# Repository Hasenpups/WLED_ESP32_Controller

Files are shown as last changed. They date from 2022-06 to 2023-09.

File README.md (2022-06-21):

Shield: [][cc-by-nc-sa]

This work is licensed under a
[Creative Commons Attribution-NonCommercial-ShareAlike 4.0 International License][cc-by-nc-sa].

[][cc-by-nc-sa]

[cc-by-nc-sa]: http://creativecommons.org/licenses/by-nc-sa/4.0/
[cc-by-nc-sa-image]: https://licensebuttons.net/l/by-nc-sa/4.0/88x31.png
[cc-by-nc-sa-shield]: https://img.shields.io/badge/License-CC%20BY--NC--SA%204.0-lightgrey.svg

## Donations / Spenden
If somebody wants to support me for upcoming projects :)  
- PayPal:  
- Amazon Giftcard: https://www.amazon.de/Amazon-Gutschein-per-E-Mail-Amazon/dp/B0054PDOV8 - stefan.riese@me.com

# WLED ESP32 Controller
This board is designed to connect addressable LEDs/Neopixel strips and handle them with the WLED firmware. Other firmware can be used as well.

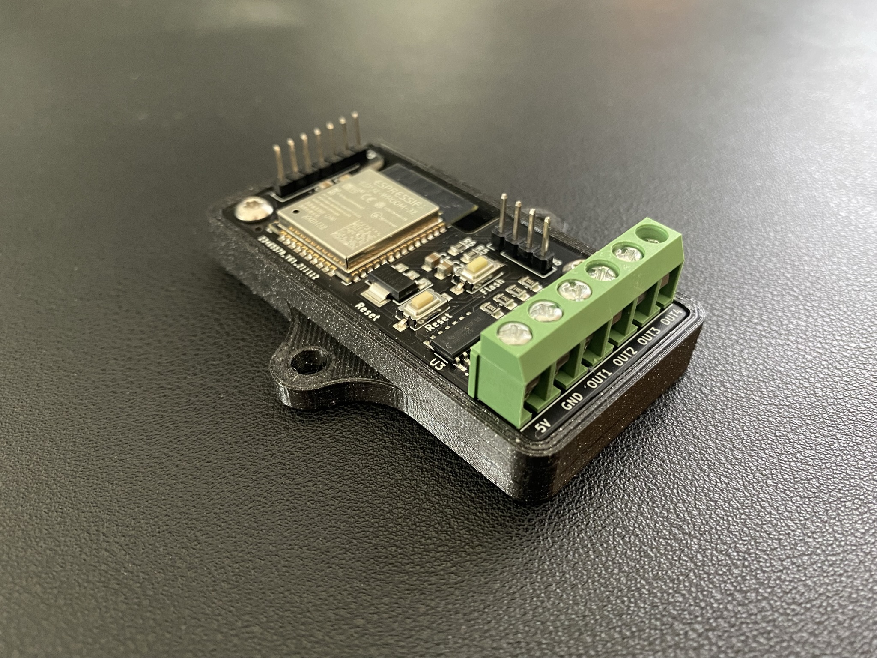
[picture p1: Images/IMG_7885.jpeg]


## Features
- 5V/GND connector for input voltage
- 4 output lines for LED data or relais
- level shifter for all 4 outputs (3.3V -> 5V )
- resistor for data lines
- support for LED strips with clock signal
- connector for microphone sensor or button input (ADC1, GND, 3.3V, IN1, GND, IN2, GND)
- connector to flash firmware with CP2104 (3.3V, TX, RX, GND)

## BOM
- 1 x WLED ESP32 Controller presoldered from https://jlcpcb.com/

|Comment|Designator|Footprint|LCSC
|---|---|---|---
10µ|C1,C3|Capacitor_SMD:C_0805_2012Metric_Pad1.18x1.45mm_HandSolder|C15850
47µ|C2|Capacitor_SMD:C_0805_2012Metric_Pad1.18x1.45mm_HandSolder|C16780
100n|C4,C5|Capacitor_SMD:C_0805_2012Metric_Pad1.18x1.45mm_HandSolder|C49678
MountingHole|H1,H2|MountingHole:MountingHole_3.2mm_M3_DIN965|
Conn_01x06_Female|J1|TerminalBlock:TerminalBlock_bornier-6_P5.08mm|
Conn_01x04_Female|J2|Connector_PinHeader_2.54mm:PinHeader_1x04_P2.54mm_Vertical|
Conn_01x07_Female|J3|Connector_PinHeader_2.54mm:PinHeader_1x07_P2.54mm_Vertical|
Jumper_NO_Small|JP1,JP2,JP3,JP4|Jumper:SolderJumper-2_P1.3mm_Open_RoundedPad1.0x1.5mm|
330|R1,R2,R3,R4|Resistor_SMD:R_0805_2012Metric_Pad1.20x1.40mm_HandSolder|C17630
10K|R5,R6|Resistor_SMD:R_0805_2012Metric_Pad1.20x1.40mm_HandSolder|C17414
Reset|SW1|Button_Switch_SMD:SW_SPST_CK_RS282G05A3|C354943
Flash|SW2|Button_Switch_SMD:SW_SPST_CK_RS282G05A3|C354943
AMS1117-3.3|U1|Package_TO_SOT_SMD:SOT-223-3_TabPin2|C6186
ESP32-WROOM-32|U2|RF_Module:ESP32-WROOM-32|C82899
SN74AHCT125D|U3|WLED_ESP32:SOIC127P600X175-14N|C155176

- 3 x 2-pin screw terminal (https://www.amazon.de/gp/product/B08JB6SSCJ)
- 1 x 4-pin header male
- 1 x 7-pin header male

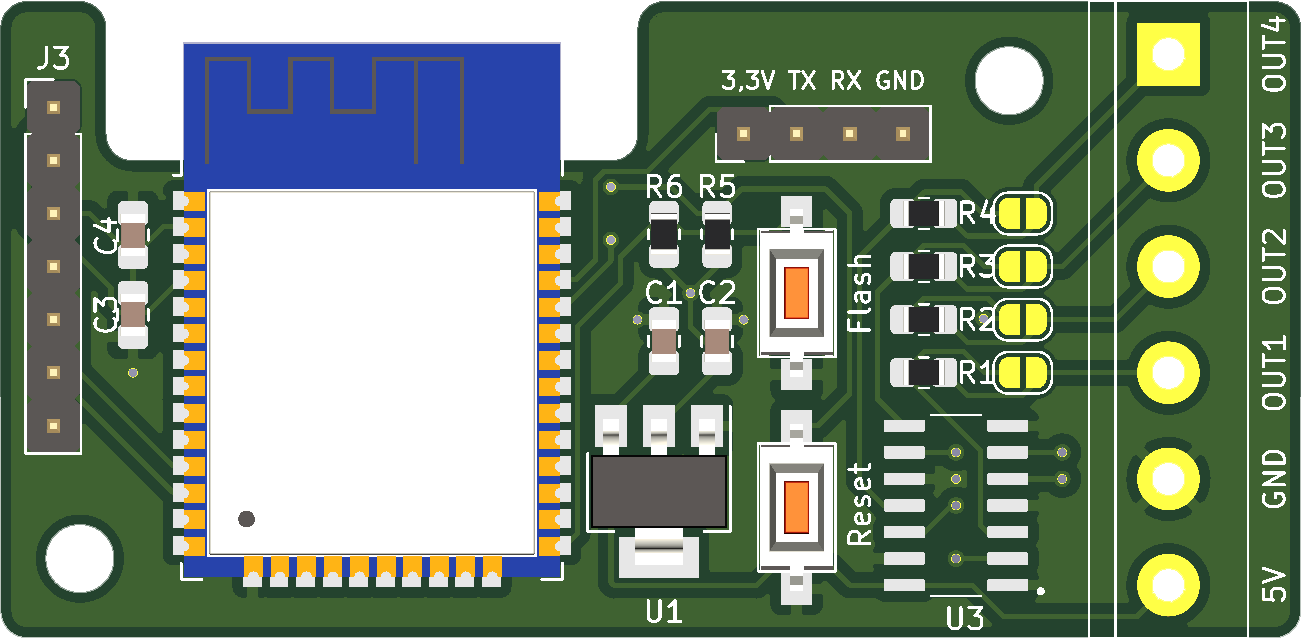
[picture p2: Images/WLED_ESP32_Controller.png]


## Wiring diagram
- https://github.com/Hasenpups/WLED_ESP32_Controller/blob/main/WLED_ESP32_Controller.pdf

## Software
- WLED: https://github.com/Aircoookie/WLED/releases
- Sound Reactive WLED: https://github.com/atuline/WLED/releases

## How to flash software
- Connect USB-UART bridge to 3.3V, TX, RX and GND
    - https://de.aliexpress.com/item/1005002689033373.html
    - https://www.makershop.de/module/kommunikation-module/micro-usb-uart-ttl/
- Press and hold "Flash" button
- Press "Reset" button and release
- Release "Flash" button
- Open https://install.wled.me/
- Click "Install"
- Select COM port of USB-UART bridge
- Wait until finished

## WLED configuration
- OUT1 - IO16
- OUT2 - IO17
- OUT3 - IO18
- OUT4 - IO19
- Microphone input - IO36
- Button input 1 - IO26
- Button input 2 - IO27

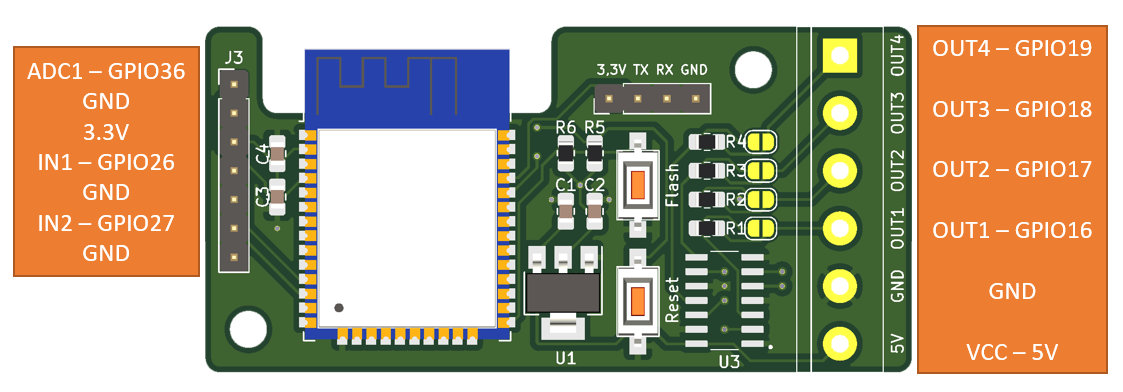
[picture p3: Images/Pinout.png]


## Case
- https://www.prusaprinters.org/prints/124223-wled-controller-base-housing
- https://www.printables.com/model/163438-housing-for-esp32-wled-controller

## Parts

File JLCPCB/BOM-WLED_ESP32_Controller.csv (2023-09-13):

Comment | Designator | Footprint | LCSC
AMS1117-3.3 | U1 | SOT-223-3_TabPin2 | C6186
47µ | C2 | C_0805_2012Metric_Pad1.18x1.45mm_HandSolder | C16780
10K | R5 | R_0805_2012Metric_Pad1.20x1.40mm_HandSolder | C17414
10µ | C3 | C_0805_2012Metric_Pad1.18x1.45mm_HandSolder | C15850
100n | C4 | C_0805_2012Metric_Pad1.18x1.45mm_HandSolder | C49678
Reset | SW1 | SW_SPST_CK_RS282G05A3 | C354943
SN74AHCT125D | U3 | SOIC127P600X175-14N | C155176
330 | R1 | R_0805_2012Metric_Pad1.20x1.40mm_HandSolder | C17630
330 | R2 | R_0805_2012Metric_Pad1.20x1.40mm_HandSolder | C17630
330 | R3 | R_0805_2012Metric_Pad1.20x1.40mm_HandSolder | C17630
330 | R4 | R_0805_2012Metric_Pad1.20x1.40mm_HandSolder | C17630
10K | R6 | R_0805_2012Metric_Pad1.20x1.40mm_HandSolder | C17414
10µ | C1 | C_0805_2012Metric_Pad1.18x1.45mm_HandSolder | C15850
Flash | SW2 | SW_SPST_CK_RS282G05A3 | C354943
ESP32-WROOM-32 | U2 | ESP32-WROOM-32 | C82899

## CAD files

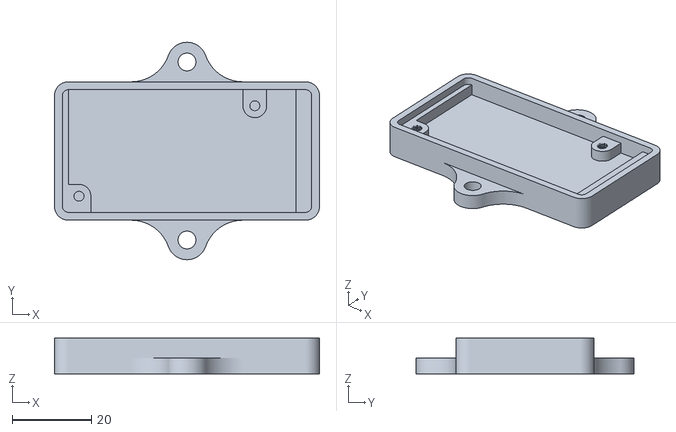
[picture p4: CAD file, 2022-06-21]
Case/WLED_ESP32_Controller_Case.stl
67.0 x 55.0 x 9.00

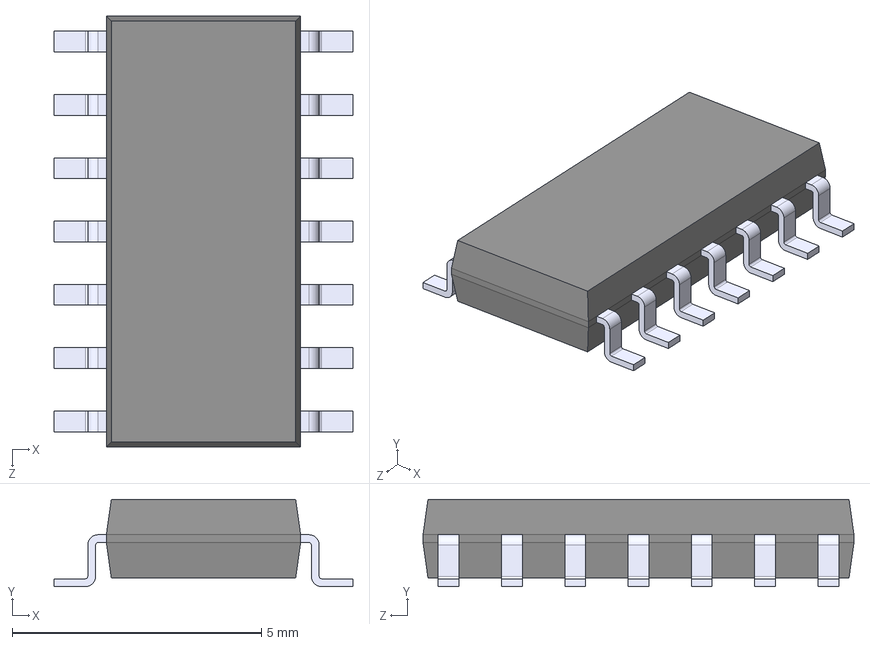
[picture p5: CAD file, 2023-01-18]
KiCad/Project_Libraries/Project_3DModels/SN74AHCT125D.step
6.00 x 1.75 x 8.65 mm

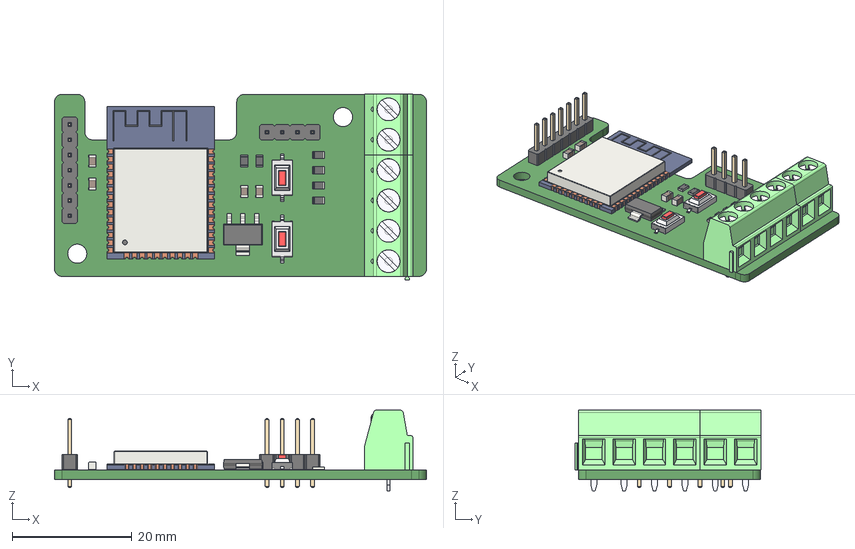
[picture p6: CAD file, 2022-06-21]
WLED_ESP32_Controller.step
62.2 x 31.0 x 13.5 mm
mkdsn_1.5-4-5.08
mkdsn_1.5-2-5.08

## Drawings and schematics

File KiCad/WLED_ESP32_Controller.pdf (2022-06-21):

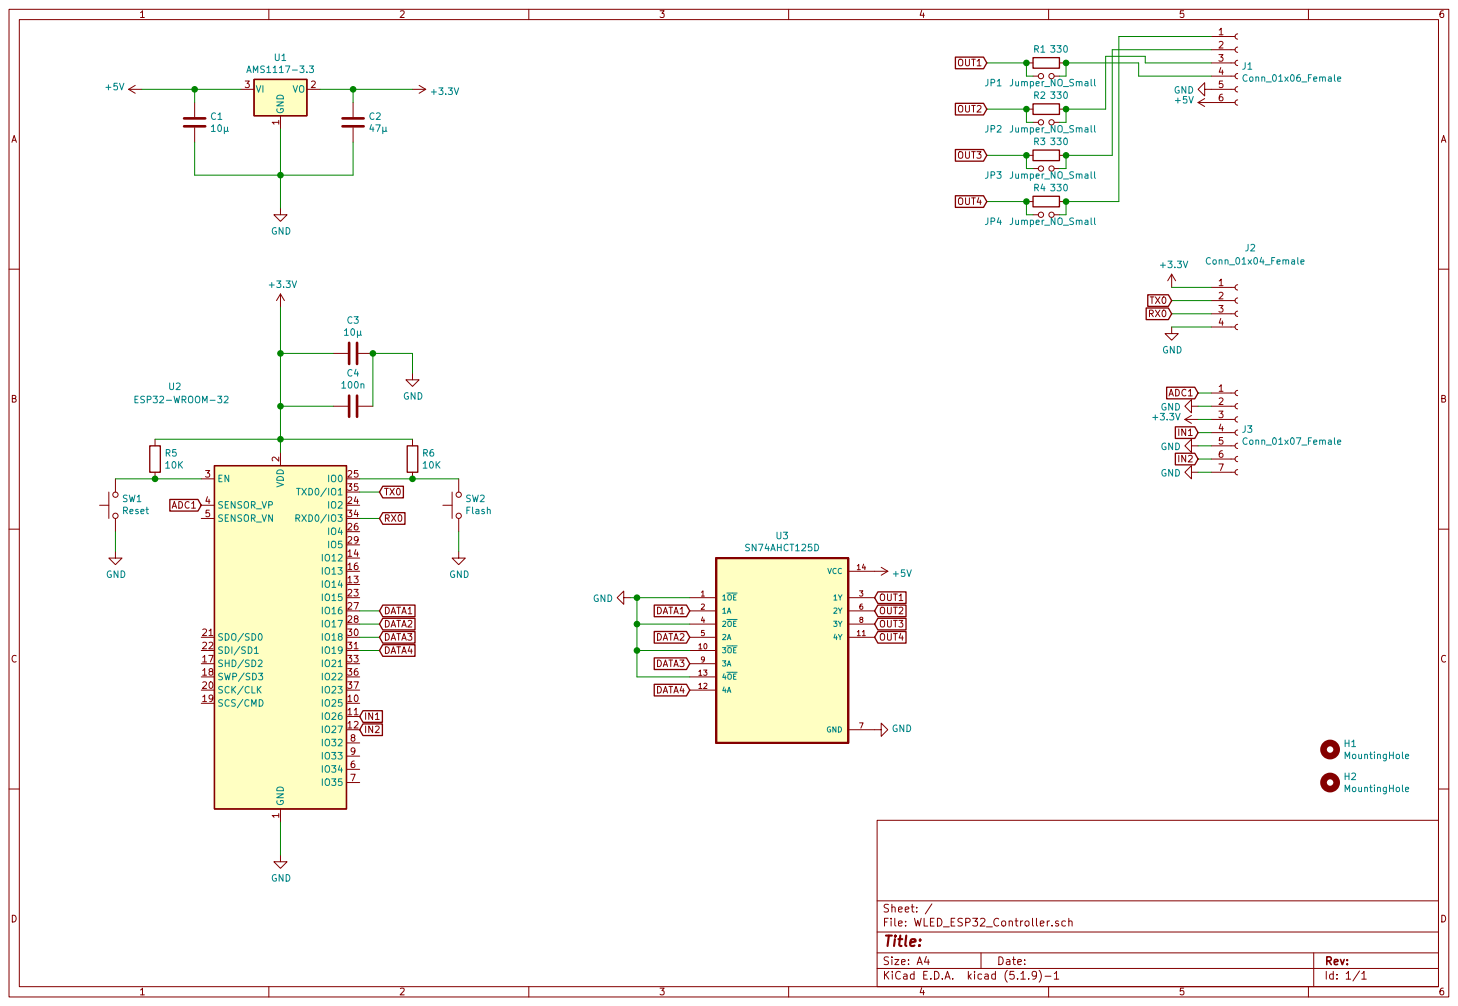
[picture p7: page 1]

2 SCK/CLK 20 SDO/SD0 21 SDI/SD1 22

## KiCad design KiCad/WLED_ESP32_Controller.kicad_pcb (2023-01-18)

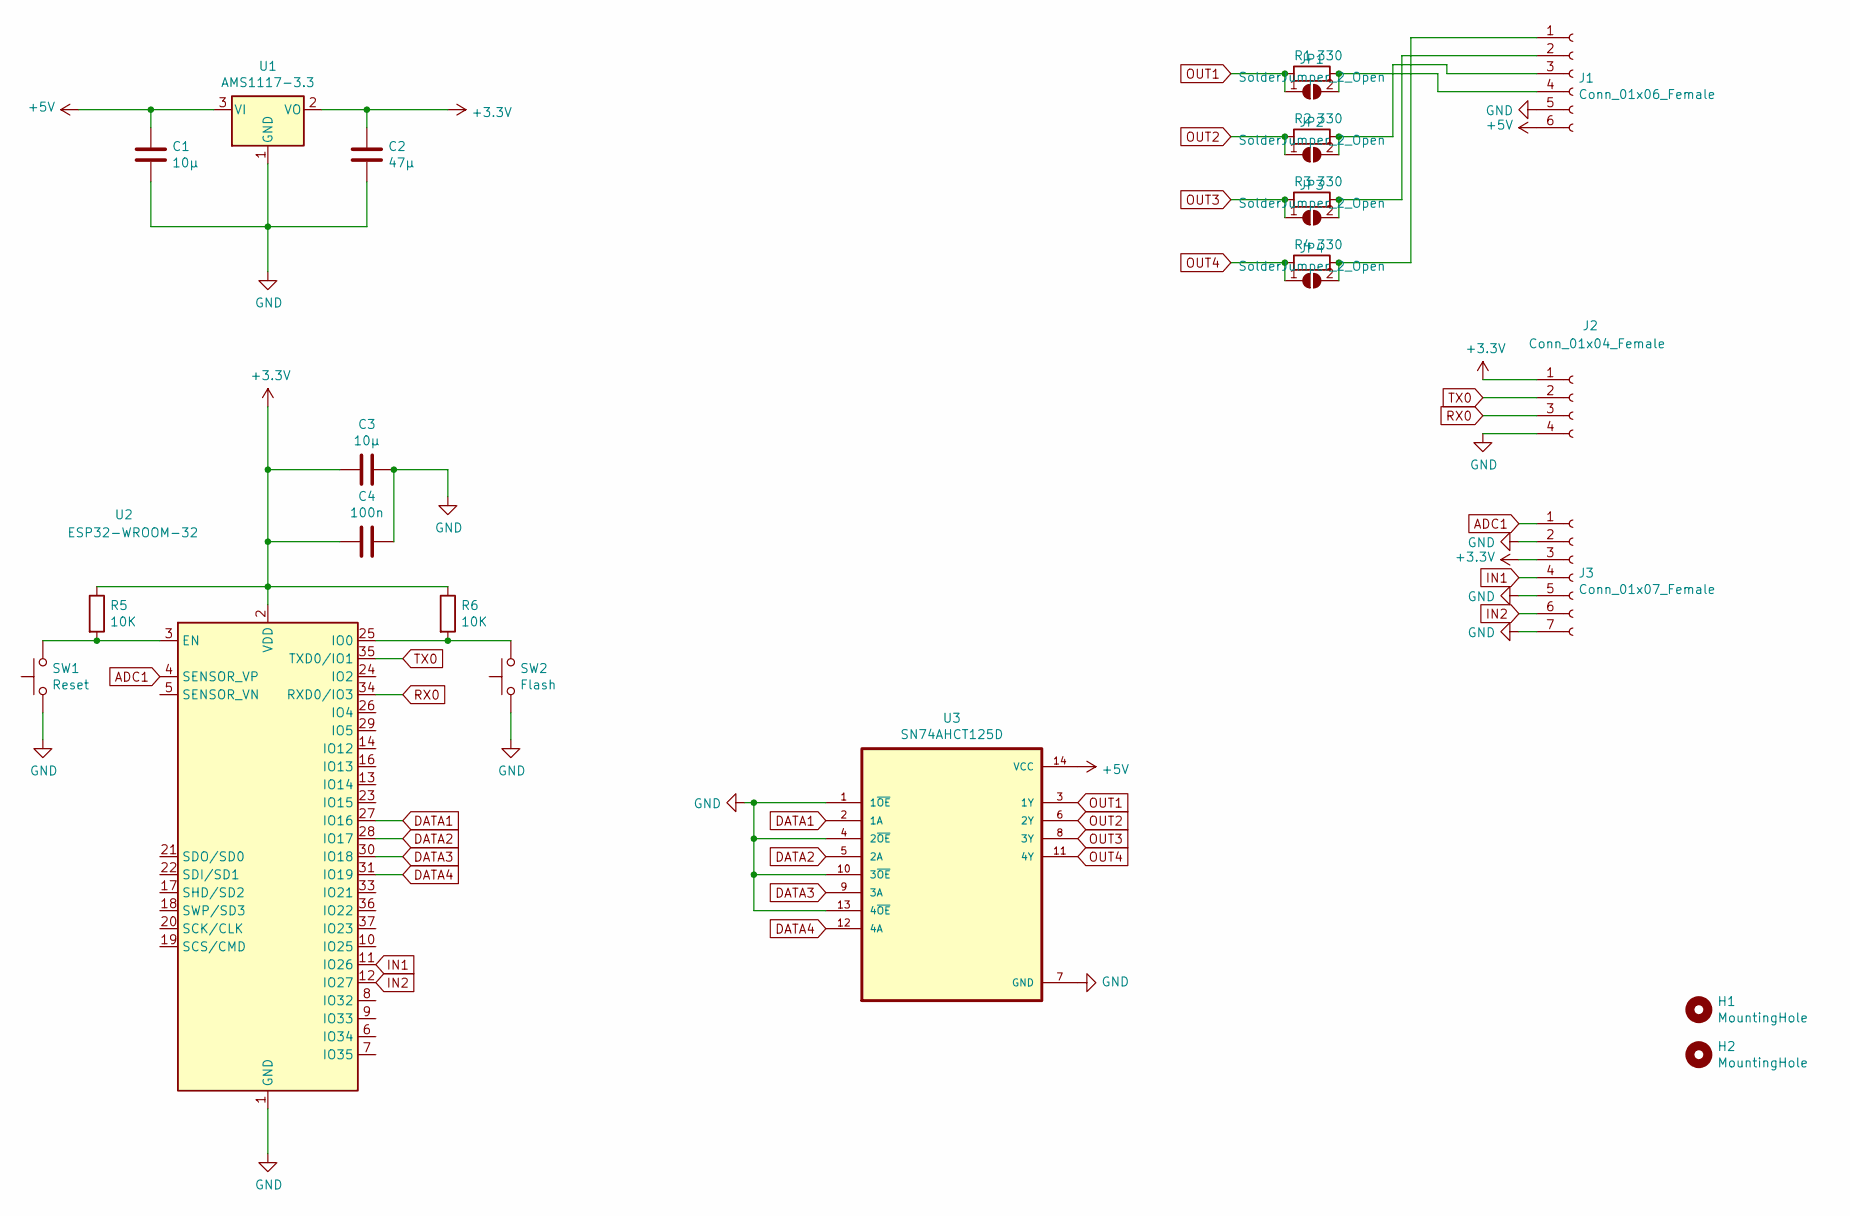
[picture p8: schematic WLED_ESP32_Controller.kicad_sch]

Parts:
C1, C3: 10µ; C_0805_2012Metric_Pad1.18x1.45mm_HandSolder
C2: 47µ; C_0805_2012Metric_Pad1.18x1.45mm_HandSolder
C4: 100n; C_0805_2012Metric_Pad1.18x1.45mm_HandSolder
H1, H2: MountingHole; MountingHole_3.2mm_M3_DIN965
J1: Conn_01x06_Female; TerminalBlock_bornier-6_P5.08mm
J2: Conn_01x04_Female; PinHeader_1x04_P2.54mm_Vertical
J3: Conn_01x07_Female; PinHeader_1x07_P2.54mm_Vertical
JP1, JP2, JP3, JP4: SolderJumper_2_Open; SolderJumper-2_P1.3mm_Open_Pad1.0x1.5mm
R1, R2, R3, R4: 330; R_0805_2012Metric_Pad1.20x1.40mm_HandSolder
R5, R6: 10K; R_0805_2012Metric_Pad1.20x1.40mm_HandSolder
SW1: Reset; SW_SPST_CK_RS282G05A3
SW2: Flash; SW_SPST_CK_RS282G05A3
U1: AMS1117-3.3; SOT-223-3_TabPin2
U2: ESP32-WROOM-32
U3: SN74AHCT125D; SOIC127P600X175-14N

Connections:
+3.3V: C2.1, C3.2, C4.2, J2.1, J3.3, R5.1, R6.1, U1.2 (VO), U2.2 (VDD)
+5V: C1.1, J1.6, U1.3 (VI), U3.14 (VCC)
ADC1: J3.1, U2.4 (SENSOR_VP)
DATA1: U2.27 (IO16), U3.2 (1A)
DATA2: U2.28 (IO17), U3.5 (2A)
DATA3: U2.30 (IO18), U3.9 (3A)
DATA4: U2.31 (IO19), U3.12 (4A)
GND: C1.2, C2.2, C3.1, C4.1, J1.5, J2.4, J3.2, J3.5, J3.7, SW1.1, SW2.1, U1.1 (GND), U2.1 (GND), U2.15 (GND), U2.38 (GND), U2.39 (GND), U3.1 (1~OE), U3.4 (2~OE), U3.7 (GND), U3.10 (3~OE), U3.13 (4~OE)
IN1: J3.4, U2.11 (IO26)
IN2: J3.6, U2.12 (IO27)
unnamed: J1.1, JP4.2 (B), R4.2
unnamed: J1.2, JP3.2 (B), R3.2
unnamed: J1.3, JP2.2 (B), R2.2
unnamed: J1.4, JP1.2 (B), R1.2
unnamed: R5.2, SW1.2, U2.3 (EN)
unnamed: R6.2, SW2.2, U2.25 (IO0)
OUT1: JP1.1 (A), R1.1, U3.3 (1Y)
OUT2: JP2.1 (A), R2.1, U3.6 (2Y)
OUT3: JP3.1 (A), R3.1, U3.8 (3Y)
OUT4: JP4.1 (A), R4.1, U3.11 (4Y)
RX0: J2.3, U2.34 (RXD0/IO3)
TX0: J2.2, U2.35 (TXD0/IO1)

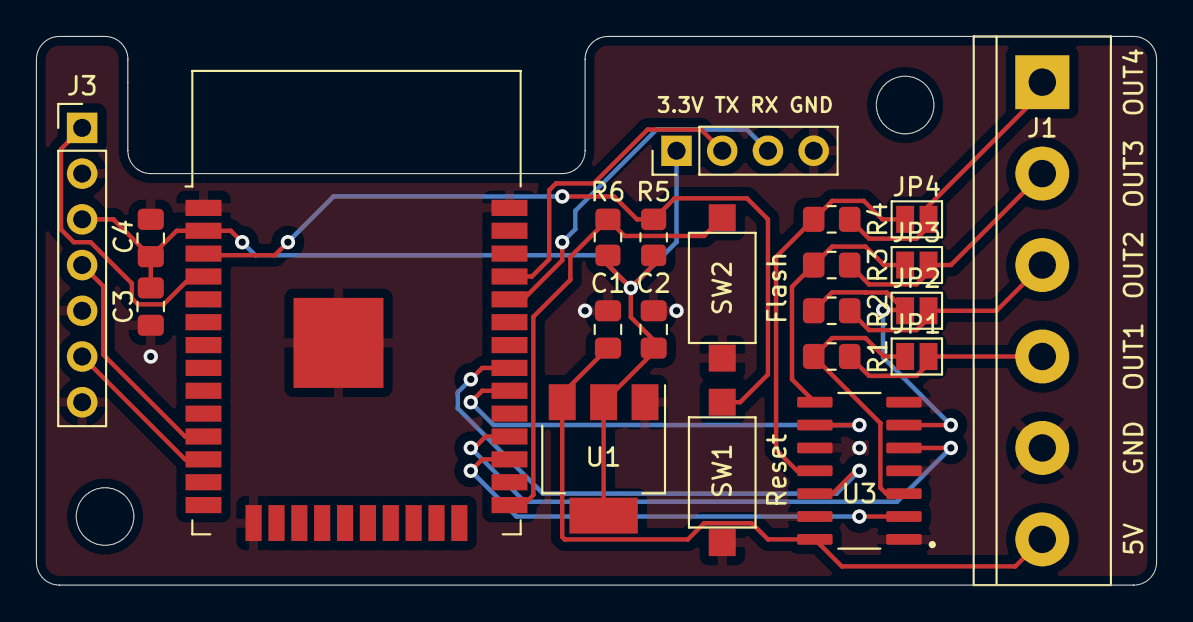
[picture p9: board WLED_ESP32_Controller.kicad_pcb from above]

Board: 2 copper layers, 62.2 x 30.5 mm, 24 parts (0 on the bottom side), 22 nets.

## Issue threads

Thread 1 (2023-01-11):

Power

espuno, 2023-01-11:
Your 5v trace is much too thin.
The thickness of the trace must match the current.

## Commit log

2022-06-21 - reupload
    [WLED_ESP32_Controller.step]
2023-01-18 - add KiCad files
    [JLCSMT_BOM.csv, JLCSMT_BOM_74AHCT32.csv, SN74AHCT125D.step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]
2023-01-18 - update URL
    [WLED_ESP32_Controller.kicad_pcb]

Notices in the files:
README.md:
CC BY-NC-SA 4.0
